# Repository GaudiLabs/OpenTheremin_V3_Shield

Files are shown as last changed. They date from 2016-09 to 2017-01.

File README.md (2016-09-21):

# OpenTheremin_V3_Shield
Open Source Theremin Instrument

Schematics, printed circuit board (PCB) design, bill of materials (BOM) for the Open.Theremin.V3 arduino shield.
For software see separate git repository.

### Don't click on the files!
Click on the "Download ZIP" Button to the right or [Click here](https://github.com/GaudiLabs/OpenTheremin_Shield/archive/master.zip) 
Then unpack the archive.

### Open Source Theremin based on the Arduino Platform

Open.Theremin.V3 is an arduino shield to build the legendary music instrument invented by Leon Theremin back in 1920. The theremin is played with two antennas, one to control the pitch and one for volume. The electronic shield with two ports to connect those antennas comprises two heterodyne oscillators to measure the distance of the hand to the antenna when playing the instrument. The resulting signal is fed into the arduino. After linearization and filtering the arduino generates the instruments sound that is then played through a high quality digital analog audio converter on the board. The characteristics of the sound can be determined by a wave table on the arduino.

For more info on the open source project and on availability of ready made shield see:

http://www.gaudi.ch/OpenTheremin/

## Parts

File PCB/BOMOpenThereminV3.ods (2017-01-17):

BOM OpenTheremin V3
Designator | Quantity | Package | Designation |  | Order No
U7 | 1 | SOIC-14_N | MCP4922-E/SL | mouser | 579-MCP4922T-E/SL
U4 | 1 | SOIC-14_N | AC74HC74 | mouser | 771-74HC74D-T
U5 | 1 | SOIC-14_N | CD4069 | mouser | 771-HEF4069UBTD-T
U2,U3 | 2 | SOIC-16_N | 74HC4060 | farnell | 771-74HC4060D-T ? / 2438691
U6 | 1 | SOIC-08_N | MCP4921-E/SN | mouser | 579-MCP4921T-E/SN
U8 | 1 | SOIC-08_N | MCP6002 (LM358) | mouser | 579-MCP6002T-I/SN
X1 | 1 | Crystal_HC49-SD_SMD | 8MHz | mouser | 717-9C-8.000MAAJ-T
X2 | 1 | Crystal_HC49-SD_SMD | 7.3721MHz | mouser | 717-9C-7.3728MAAJ-T
C2,C3, C9,C10 | 4 | 0805G | 150pF | mouser | 603-CC805JRNPO9BN151
C5, C12 | 2 | 0805G | 470pF | mouser | 603-CC805JRNPO9BN471
C15,C16,C17,C18 | 4 | 0805G | 33pF | mouser | 603-CC805JRNPO9BN330
C22 | 1 | 0805G | 47nF | mouser | 603-CC0805JR7BB473
C6,C13,C20,C21,C23, C24,C25,C26,C27,C28 | 10 | 0805G | 100nF | mouser | 603-CC805KRX7R8BB104
C29 | 1 | 0805G | 10uF | mouser | 603-CC805KRX5R5BB106
C1 | 1 | 0805G | 220pF | mouser | 603-CC805JRNPO9BN221
C8 | 1 | 0805G | 330pF | mouser | 603-CC805JRNPO9BN331
C4 | 1 |  | do not assemble
C11 | 1 | 0805G | 10pF | mouser | 603-CC805JRNPO9BN100
C7 |  |  | do not assemble
C14 |  |  | do not assemble
D1,D2 | 2 | SOT-23 | BB914 | mouser | 726-BB914E6327
D3 | 1 | LED | LED square 5mm red | Reichelt / ebay | L-1553HDT (V 530)
D4 | 1 | LED | LED square 5mm yellow | Reichelt / ebay | L-1553YDT (V 533)
L1,L2 | 2 | COIL | 1mH | mouser | 810-NL453232T-102JPF
R1,R5,R11,R13 | 4 | 0805G | 4.7M |  | 603-RC0805FR-074M7L
R12,R14 | 2 | 0805G | 470 |  | 603-RC0805FR-07470RL
R18,R19 | 2 | 0805G | 270 |  | 603-RC0805FR-07270RL
R2,R6 | 2 | 0805G | 2.2k |  | 603-RC0805FR-072K2L
R17 | 1 | 0805G | 2.2k |  | 603-RC0805FR-072K2L
R3,R4,R7,R8,R15,R16 | 6 | 0805G | 100k |  | 603-RC0805FR-07100KL
SW1 | 1 | SW_PUSH | Tactile Switches 12x12 SMT | Mouser / aliexpress / ebay | 706-95C12A4GWRT
P1,P2,P3,P4 | 4 | POT | 10k | mouser | 652-PTV09A-4020UB103 (104)
Y7 | 1 | PLUG3_5_SMD | Switchcraft, SMT 3.5 STEREO | mouser | 502-35RASMT2BHNTRX
Y3, Y4, Y5, Y6 | 1 | Pinheaders 2.54 |  | reichelt | SL 1X36G 2,54
 | 2 | Antenna Plug Standard |  | Reichelt / ebay | BS 40SA RT
 | 2 | Screw M3x10 |  | Hasler.ch /bossard | BN1435.03010
 | 2 | Nut M3 |  | Hasler.ch /bossard | BN117 M3
 | 2 | Washer |  | reichelt | SKZ 3,2-100
U1 | 1 | ArduinoUNO | Arduino_UNO_R2
 | 1 | PCB | OpenTheremin PCB V3
 |  |  |  |  | Urs Gaudenz, GaudiLabs 2017

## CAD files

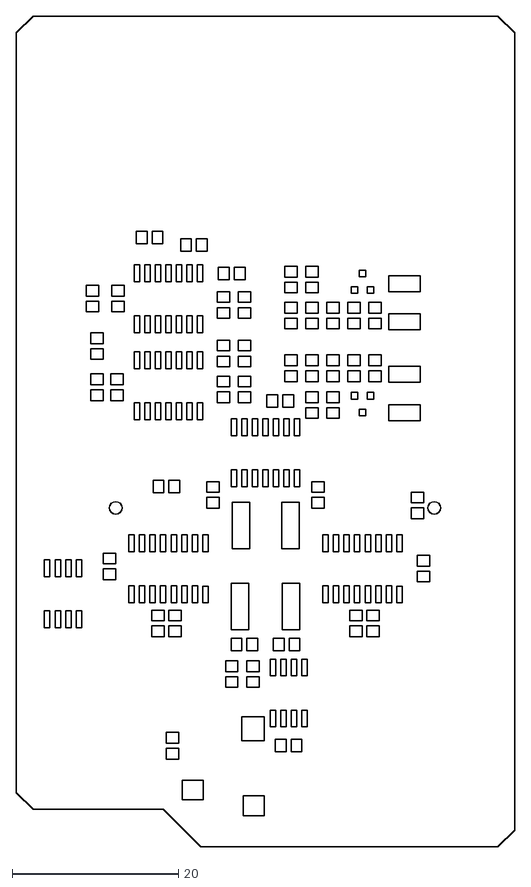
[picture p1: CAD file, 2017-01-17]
PCB/Stencli/Stencil.dxf
60.0 x 100.0

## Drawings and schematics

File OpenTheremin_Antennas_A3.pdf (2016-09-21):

# VOLUME ANTENNA

# Theremin Volume Connector

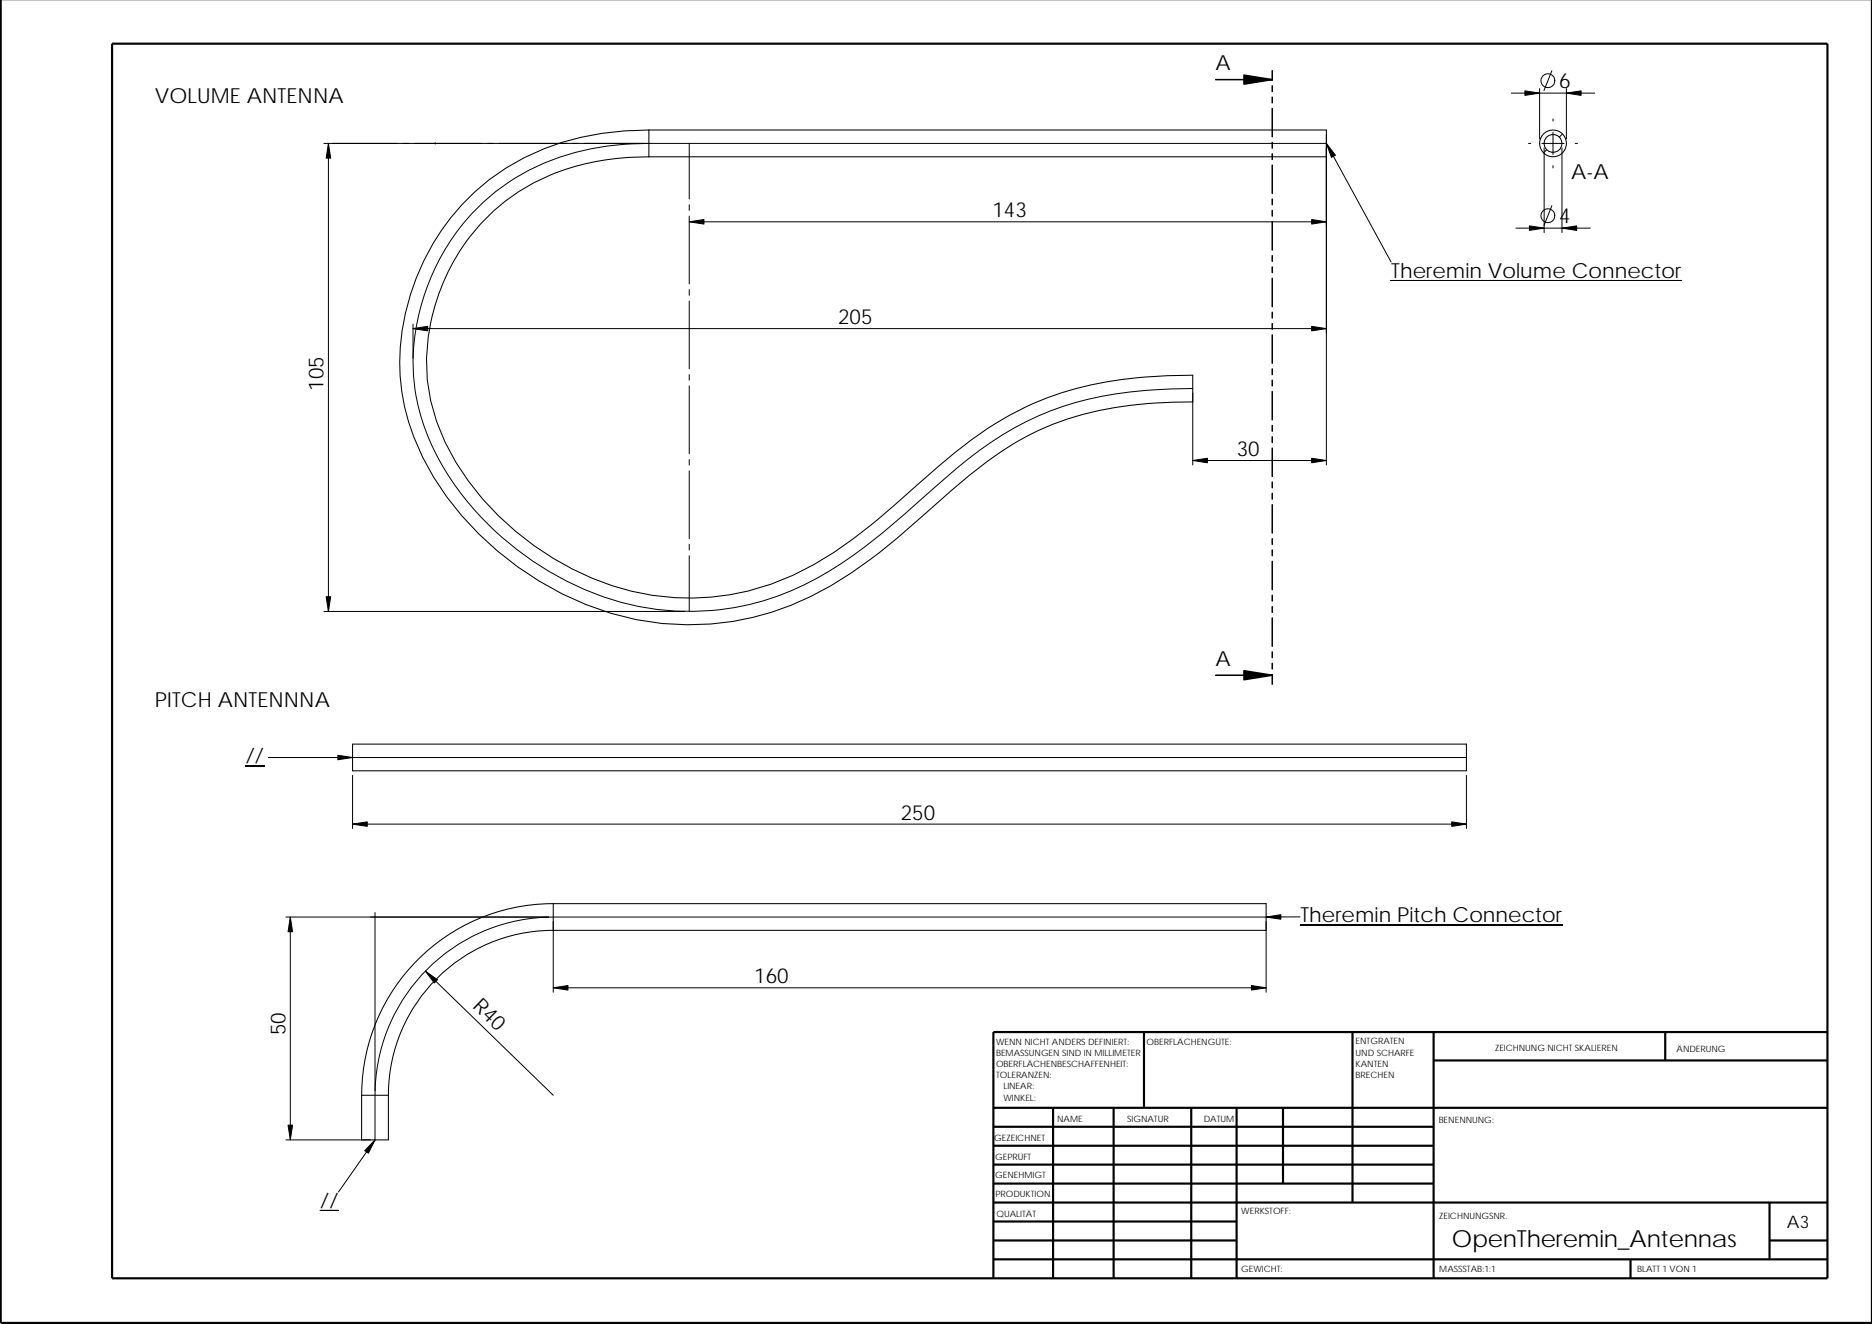
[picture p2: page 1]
PITCH ANTENNNA; GEWICHT:; MASSSTAB:1:1; BLATT 1 VON 1; ZEICHNUNG NICHT SKALIEREN; ÄNDERUNG; OBERFLÄCHENGÜTE:; ENTGRATEN; KANTEN BRECHEN; UND SCHARFE

Theremin Pitch Connector

WENN NICHT ANDERS DEFINIERT:
BEMASSUNGEN SIND IN MILLIMETER
OBERFLÄCHENBESCHAFFENHEIT:
TOLERANZEN:
LINEAR:
WINKEL:

NAME | SIGNATUR | DATUM | | | | BENENNUNG:

GEZEICHNET
GEPRÜFT
GENEHMIGT
PRODUKTION
QUALITÄT | | | | WERKSTOFF: | ZEICHNUNGSNR. OpenTheremin_Antennas | A3

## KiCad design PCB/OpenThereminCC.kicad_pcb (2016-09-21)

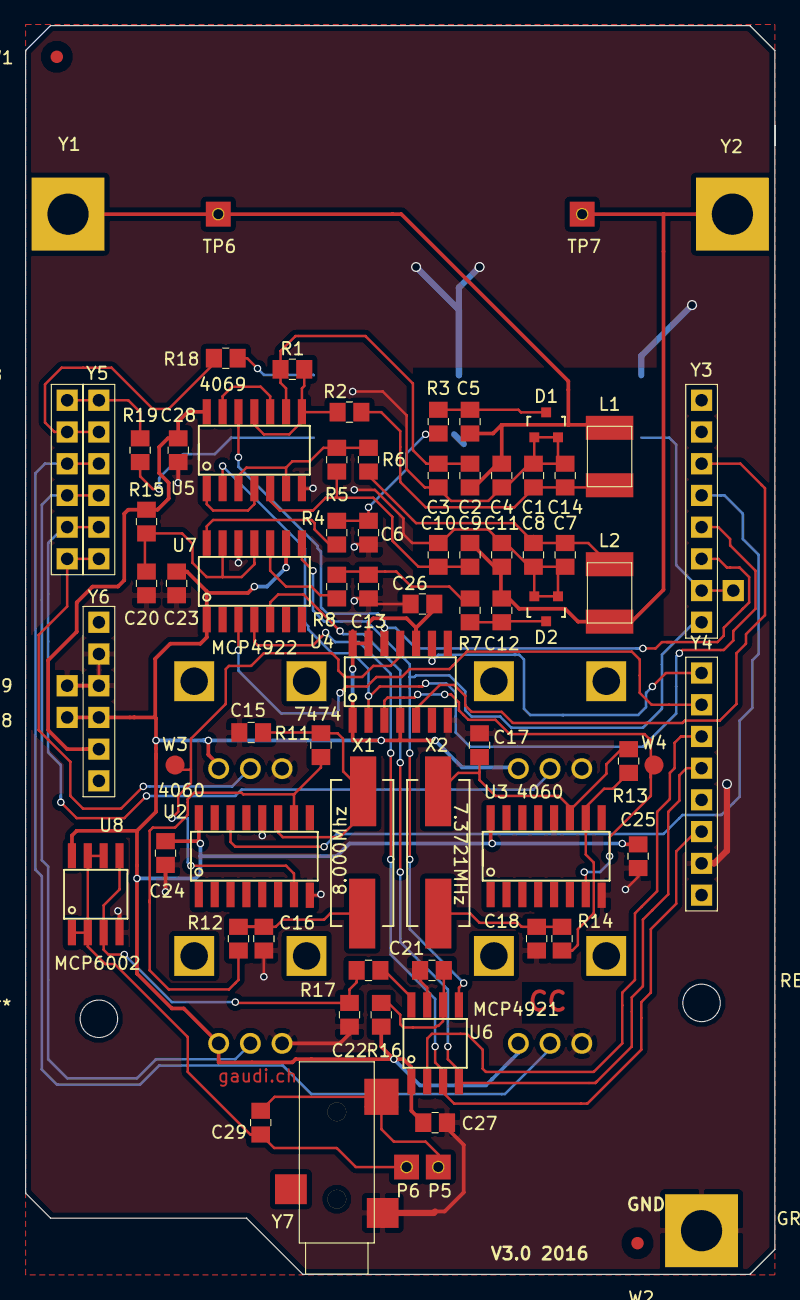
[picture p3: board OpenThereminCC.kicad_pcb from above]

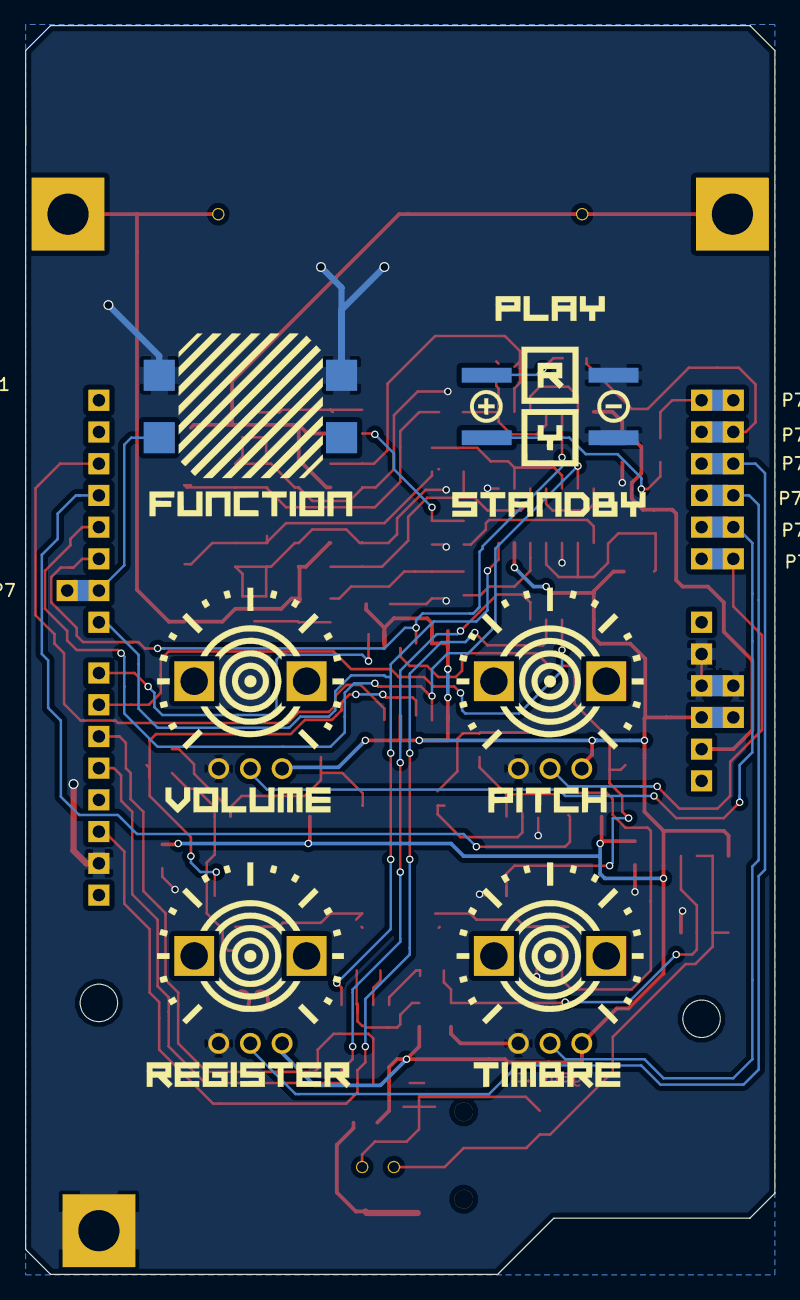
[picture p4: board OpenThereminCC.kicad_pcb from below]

Board: 2 copper layers, 60.0 x 100.0 mm, 95 parts (17 on the bottom side), 52 nets.

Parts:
C1: 220pF 270pF?; 0805G
C2, C3, C9, C10: 150pF; 0805G
C4: 15nF?; 0805G
C5, C12: 470pF; 0805G
C6, C13, C23, C24, C25, C26, C27, C28: 100nF; 0805G
C7, C14: ?pF; 0805G
C8: 330pF; 0805G
C11: 0; 0805G
C15, C16, C17, C18: 33pF; 0805G
C20, C21: 100n; 0805G
C22: 10n; 0805G
C29: 10uF; 0805G
D1, D2: BB914; SOT-23
D3, D4: LED; LED_SQUARE_5mm
GROUND1: GND_PAD; MountPad3
L1, L2: 1mH; COIL
P1, P2, P3, P4: 10k; POT
P5: SP+; MeasurePad_Square_wHole_2mm
P6: SP-; MeasurePad_Square_wHole_2mm
P7, P7#3, P7#4, P7#5, P7#6, P7#7, P7#8, P7#9, P7#10: CONN_01X01; SMD_Pinheader_1_OT_BLANK
P7#2, P8, P9: CONN_01X01; SMD_Pinheader_1_OT
R1, R5, R11, R13: 4.7M; 0805G
R2, R6, R17: 2.2k; 0805G
R3, R4, R7, R8, R15, R16: 100k; 0805G
R12, R14, R18, R19: 470; 0805G
SW1: SW_PUSH; PUSH_BUTTON_TL3300D
TP6: PITCH ANTENNA; MeasurePad_Square_wHole_2mm
TP7: VOLUME ANTENNA; MeasurePad_Square_wHole_2mm
U1: Arduino_UNO_R2; ArduinoUNO
U2, U3: 4060; SOIC-16_N
U4: 74HC74; SOIC-14_N
U5: 4069; SOIC-14_N
U6: MCP4921-E/SN; SOIC-08_N
U7: MCP4922-E/SL; SOIC-14_N
U8: LM358 / MCP6002; SOIC-08_N
W1: FIDUCIAL1; Fiducial_1mm_Dia_2.54mm_Outer_CopperTop
W2: FIDUCIAL2; Fiducial_1mm_Dia_2.54mm_Outer_CopperTop
W3: TP1; Measurement_Point_Round-SMD-Pad_Small
W4: TP2; Measurement_Point_Round-SMD-Pad_Small
X1: 8MHz; Crystal_HC49-SD_SMD
X2: 7.3721MHz; Crystal_HC49-SD_SMD
Y1, Y2: MountPad3
Y3, Y4: CONN_01X08; SMD_Pinheader_8_OT
Y5, Y6, Y8: CONN_01X06; SMD_Pinheader_6_OT
Y7: PLUG_3_5_SMD; PLUG3_5_SwitchCraft_2B

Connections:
A0: P1.2, Y5.6, Y8.6
A1: P2.2, Y5.5, Y8.5
A2: P3.2, Y5.4, Y8.4
A3: P4.2, Y5.3, Y8.3
BUT: P7#2.1, SW1.1, Y3.7
DAC2_CS: U7.3, Y4.2
DAC_CS: U6.2, Y4.3
DAC_DI: U6.4, U7.5, Y4.4
DAC_LATCH: U6.5, U7.8, Y3.8
DAC_SCK: U6.3, U7.4, Y4.6
F_PITCH: U4.9, Y4.1
F_VOL: U4.5, Y3.3
GND: C1.2, C3.2, C4.2, C6.2, C7.2, C8.2, C10.2, C11.2, C13.2, C14.2, C15.2, C16.2, C17.2, C18.2, C20.2, C21.2, C22.2, C23.2, C24.2, C25.2, C26.2, C27.2, C28.2, D1.1, D1.2, D2.1, D2.2, D3.1, D4.1, GROUND1.1, P1.1, P2.1, P3.1, P4.1, P9.1, SW1.2, U2.8, U2.12, U3.8, U3.12, U4.7, U5.7, U6.7, U7.12, U8.4, Y4.7, Y6.2, Y6.3, Y7.1
LED_GREEN: R18.2, Y5.2, Y8.2
LED_RED: R19.2, Y5.1, Y8.1
unnamed: C1.1, C14.1, L1.2, R2.1
unnamed: C2.1, C4.1, C5.1, L1.1, TP6.1, Y1.1
unnamed: C2.2, C3.1, R1.2, U5.9
unnamed: C5.2, D1.3, R3.2
unnamed: C6.1, R3.1, R4.1
unnamed: C7.1, C8.1, L2.2, R6.1
unnamed: C9.2, C10.1, R5.2, U5.5
unnamed: C9.1, C11.1, C12.1, L2.1, TP7.1, Y2.1
unnamed: C12.2, D2.3, R7.2
unnamed: C13.1, R7.1, R8.1
unnamed: C15.1, R11.2, U2.11, X1.1
unnamed: C16.1, R12.1, X1.2
unnamed: C17.1, R13.2, U3.11, X2.1
unnamed: C18.1, R14.1, X2.2
unnamed: C21.1, R16.1, U6.6
unnamed: C22.1, R17.2, U8.3, U8.5
unnamed: C29.1, P6.1, U8.1, U8.2, U8.6, U8.7
unnamed: C29.2, P5.1, Y7.3
unnamed: D3.2, R18.1
unnamed: D4.2, R19.1
unnamed: R1.1, R2.2, U5.8, U5.11
unnamed: R4.2, U7.14
unnamed: R5.1, R6.2, U5.3, U5.6
unnamed: R11.1, R12.2, U2.10
unnamed: R13.1, R14.2, U3.10
unnamed: R17.1, U6.8
unnamed: U2.7, U4.11, W3.1
unnamed: U3.7, U4.3, W4.1
unnamed: U5.1, U5.4
unnamed: U5.10, U5.13
SAMPLE_CLK: U2.14, Y3.4
VCC: C23.1, C24.1, C25.1, C26.1, C27.1, P1.3, P2.3, P3.3, P4.3, P8.1, R16.2, U2.16, U3.16, U4.1, U4.4, U4.10, U4.13, U4.14, U6.1, U7.1, U7.9, U8.8, Y6.4
VDD: C28.1, R15.2, U5.14, Y6.5
VO_PITCH: U4.12, U5.12, Y3.6
VO_VOL: U4.2, U5.2, Y3.5
VoutB: R8.2, U7.10
VrefB: C20.1, R15.1, U7.11, U7.13

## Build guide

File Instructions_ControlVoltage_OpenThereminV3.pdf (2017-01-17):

### How to set up the Open.Theremin V3 for Control Voltage

The Open.Theremin is a stand alone instrument that generates sounds in different waveforms when played. Eight waveforms can be selected through the TIMBRE knob on the board. These waveforms can be reprogrammed using different software available online. To even further expand the possibilities the Open.Theremin can be set in “Control Voltage Mode” to control any sound synthesizer with an analog control voltage input (CV).

When in control voltage mode the signal of the pitch antenna is translated into an analog signal that will be output through the audio-jack on the board. The audio sound will not be available anymore. However you can always reinstall the original software to go back to normal audio-mode. The volume signal is not available on control voltage for now.

So here is how to set the Open.Theremin to control voltage mode:

1. You need to solder a pair of pinheaders to the free pads (P5 + P6) next to the audio-jack and install a jumper. You can find these jumpers in many electronic stores. Alternatively you can solder in a switch or just a short piece of cable to make the short between the two pads.

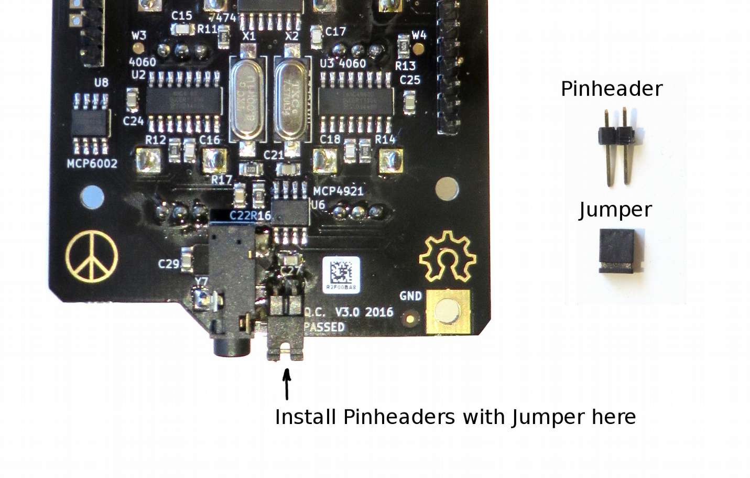
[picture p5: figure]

2. Now you need to re-upload the software with the modification for the control voltage mode. With the newest Open.Theremin V3 software loaded in the Arduino IDE go to the tab named “build.h” and change the following line from a 0 to a 1

#define CV_ENABLED 1

Now re-upload the software (for details see the Open.Theremin V3 instruction manual).

Your theremin will now generate analog values in the range of 0-5 V on the left channel of the audio jack. Maybe you want to recalibrate the theremin by pressing the FUNCTION button for 3 seconds. The PITCH and REGISTER button can still be used to change the zero beat and sensitivity respectively.

For more information, documentation and source code of the open design go to: www.gaudi.ch/OpenTheremin

Open.Theremin Instruction by Urs Gaudenz, licensed under a Creative Commons Attribution 4.0 International License.
25. Oct. 2016

Additional advanced instructions:

If you want to adapt the output signal to your specific needs you can do this by modifying the following lines of code (in the “ihandlers.cpp” tab):

#if CV_ENABLED | // Generator for CV output

vPointerIncrement = min(vPointerIncrement, 4095); // vPointerIncrement is the signal of the pitch antenna mcpDacSend(vPointerIncrement); //Send result to Digital to Analogue Converter (audio out)

#else //Play sound

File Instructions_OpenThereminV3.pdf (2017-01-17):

### Open.Theremin V3 Kit

Congratulations, this is your Open.Theremin V3, the newest version of a DIY Theremin used by more than 1000 people around the world today. Happy to have you in the community of people exploring the amazing instrument initially conceived by Leon Theremin. This is a digital theremin shield for the Arduino UNO based on the original principle of heterodyne oscillators.

Some instruction on how to set it up and get the best out of the circuit:

This is the content of your Kit:

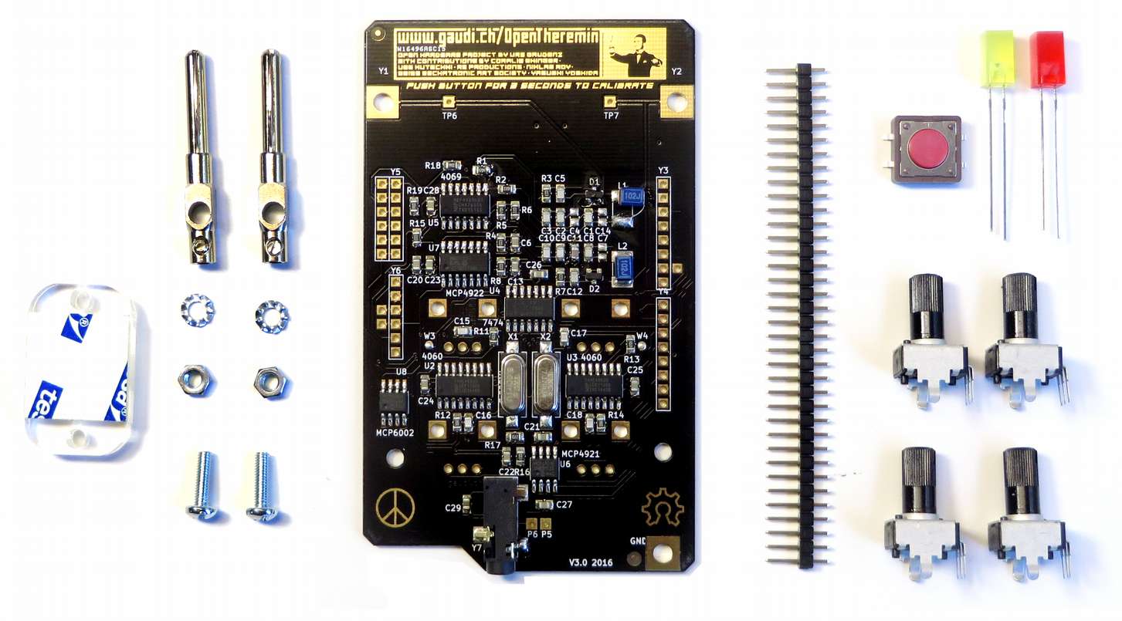
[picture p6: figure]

Mechanical Parts | Theremin Circuit Board | Electronic Components
1. Complete the shield

First solder in the pins that connect the shield to the Arduino as shown in the picture below.

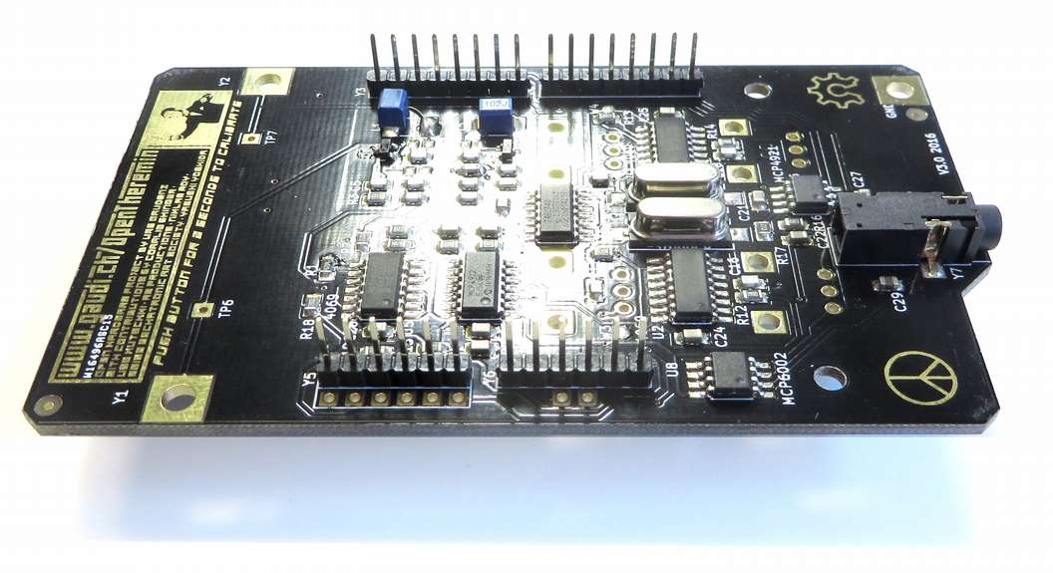
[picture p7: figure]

Next solder the push button and the two LEDs to the front. A good soldering technique for these surface mounting parts is to first put a bit of solder on one pad, then heat the solder and slide the component in place. Then solder the rest of the pads. The LED-lights have a plus and minus leg. The leg that goes to the plus side is longer. Bend the two legs of the LED to the outside and cut them to the right length. See the drawing.

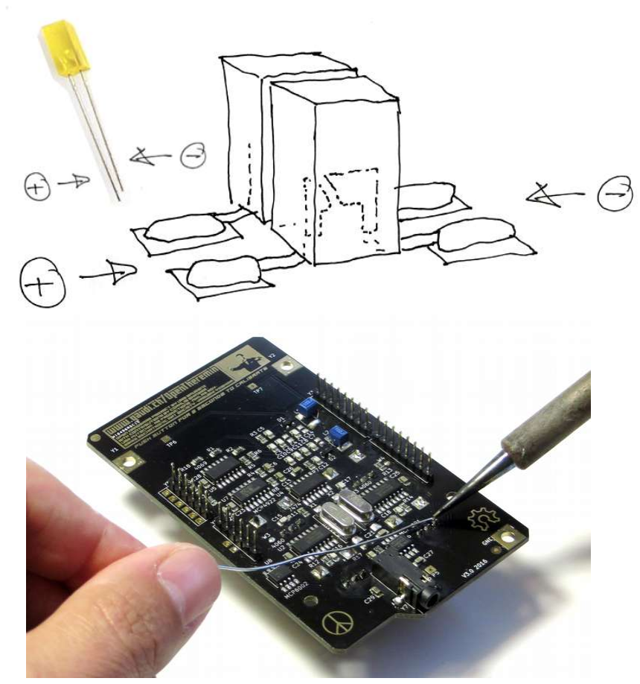
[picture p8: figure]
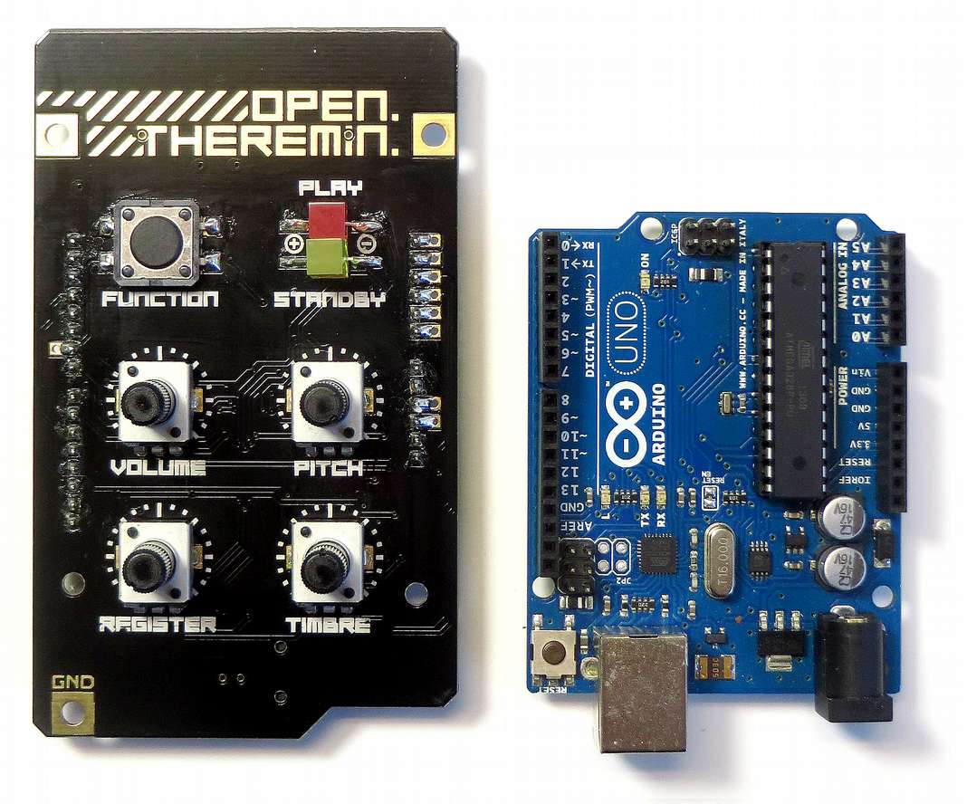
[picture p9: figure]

Finally add the four potentiometers and solder them carefully on the backside. Be sure to only put solder on the pads for the potentiometers.

Now you are ready to connect the shield on top of an Arduino UNO. Arduino UNO is a very popular open source electronic development platform that you can get from many sources on the Internet. See here for Resellers: www.arduino.cc/en/Main/Buy

2. Connect Antennas to the Open.Theremin

You can basically use any electrically conductive material as antennas. The picture shows how to connect two aluminum rods (can be found in most hardware stores) with an inner diameter of 4 mm using the supplied spring plugs (banana plugs). The total length per antenna should be around 40 to 50 cm. You can easily bend antennas form aluminum tubes of 6 mm diameter by hand to the desired shape. To build the theremin into a case you can also use stiff wire to connect the antennas.

Volume Antenna | Pitch Antenna

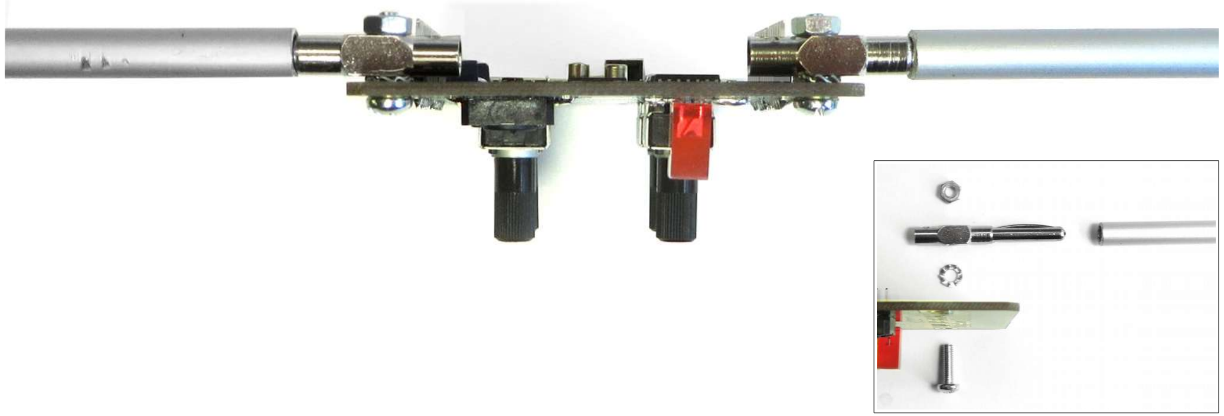
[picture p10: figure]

3. Connect the Audio Out

Use the mini jack connector on the bottom of the open.theremin shield to connect an amplifier or an active speaker.

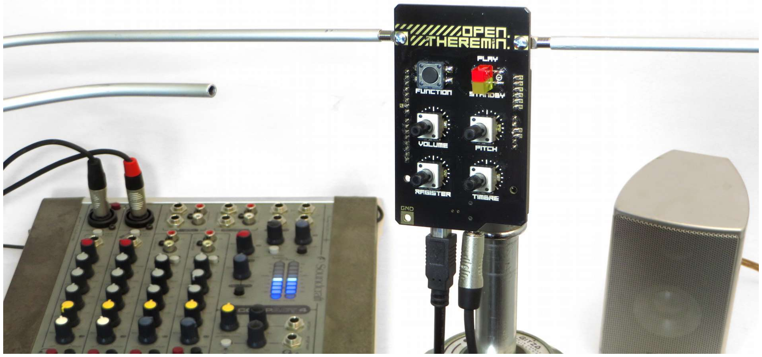
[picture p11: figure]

4. Set up and Grounding

The theremin measures smallest variations of capacities (less than 1 pico Farad). The capacity between the antenna and your hand is measured and translated into the pitch (or the volume) of the sound. The electric loop with the instrument is closed from your hand through your body, through your shoes through the floor into the ground and from ground back into the instrument. This is why proper grounding of the instrument is important.

Use any of the following methods to ground your theremin.

a. Use a grounded audio cable. If you connect your theremin to a mixer or amplifier that is grounded, the theremin is grounded through the audio cable.
b. Use a grounded power supply. You can power your theremin through the USB plug (by a device like a computer or a power adapter with USB connector) or by a separate power adapter. If the power supply is grounded the theremin is grounded as well. Notice that many USB power adapter and power supplies are not grounded.
c. Use a separate grounding wire. There is a ground pad (GND) on the open.theremin board where you can connect an extra grounding wire. Attach this wire to a grounded metallic object in your room (like a lamp or a water tube).

And not only your body is interfering with instrument,

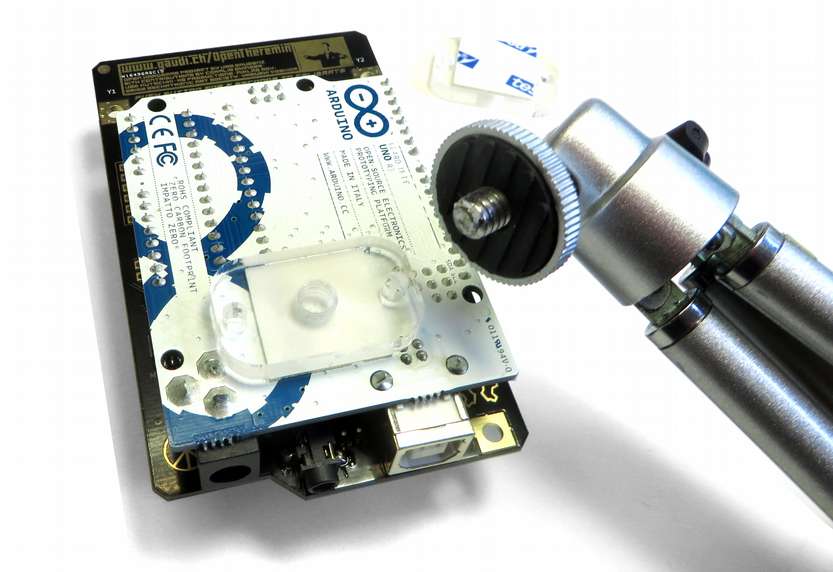
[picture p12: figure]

also a table or an object close to the theremin will add to the capacity sensed by the instrument. So best is to put up the theremin on a stand in the open space. The little acrylic adapter piece with a threaded hole (supplied in the kit) fits to commercial camera stands (1/4" UNC) and can be sticked to the back of the arduino or your own housing.

5. Programing the arduino

Connect the Arduino UNO to the computer using a standard USB cable. Note that the LED-light will only light up when the Arduino is programmed. For this download the latest Arduino IDE Software and the Open.Theremin V3 code form the links below and upload it to the board. When the upload is successful you should see the red LED-light turn on.

Instruction on how to install the Arduino programming tool and how to use it can be found here: http://arduino.cc/en/Guide/HomePage

Get the Open Theremin Code from the Git-Hub Repository by clicking the “Download ZIP” Button on this site: https://github.com/GaudiLabs/OpenTheremin_V3

6. Auto-calibration of the theremin

Theremins are very sensitive devices. This is why they need calibration before playing. The new open.theremin V3 has an electronic auto calibration built in, it makes calibration very easy. To do so follow these steps:

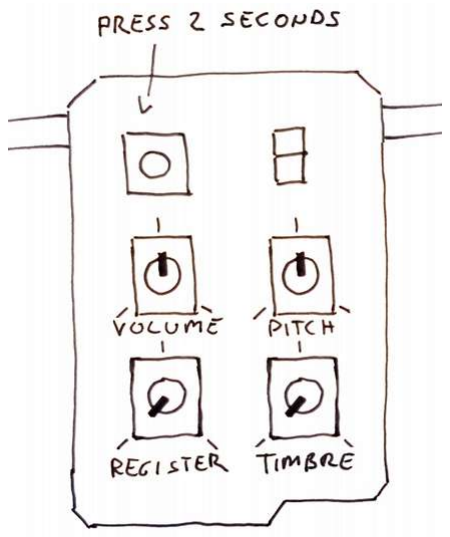
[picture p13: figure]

a. Power the theremin and let it warm up for about 10 minutes.
b. Now turn the two knobs VOLUME and PITCH to the middle position and the knobs REGISTER and TIMBRE all to the left.
c. Press the FUNCTION button on the theremin shield for about 2 second until you hear a short melody. The yellow LED-light will now start blinking and the theremin does the automatic calibration of the antennas. To not disturb the calibration step away form the theremin and wait until the red LED-light goes back on.

Now you theremin is ready to play.

The calibration values are stored in the Arduino. So you only have to do this procedure once. If however you move your theremin or feel that it is not playing well, you can always repeat the procedure to re-calibrate.

Functionality of the knobs:

The PITCH knob allows you to fine adjust the playing range of the pitch antenna (zero beat). The VOLUME changes the sensitivity of the volume antenna.
For a good introduction on how to tune the theremin see this excellent introduction by Carolina Eyck: https://youtu.be/A48fm1ZEgZU

With the REGISTER knob you can vary the sensitivity of the theremin. Turn it to the right to increase sensitivity. Note that higher sensitivity may come with more noise picked up by the antenna.

The TIMBRE knob allows you to choose from one out of 8 different sound settings.

You can mute your theremin by pressing the FUNCTION button.

For more information, documentation and source code of the open design go to: www.gaudi.ch/OpenTheremin

Open.Theremin Instruction by Urs Gaudenz, licensed under a Creative Commons Attribution 4.0 International License.

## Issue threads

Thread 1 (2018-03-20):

PCB Component and Footprint libraries missing

NathanSchenk, 2018-03-20:
In order to edit the schematic and PCB easily, KiCad needs the GaudiLabsFootprints and the GaudiLabsPartsLibrary.

Would it be possible to add these as GitHub repositories?

Thanks for your good work!

NathanSchenk, 2018-03-20:
Looks like I found the libraries in your OpenDrop repo.  They probably should still be added to this repo, or at least the location mentioned in readme.md

Thanks again, good work!

GaudiLabs, 2018-03-20:
These are libraries with many parts for all kind of projects. Is there a way to pull out only the parts that belong to the project?

Urs

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

--
Sent from my Android device with K-9 Mail. Please excuse my brevity.

NathanSchenk, 2018-03-22:
I believe the libraries could be manually adjusted, or maybe a script created to automatically trim the libraries..  I'll look into that after I'm done with my current project, unless you beat me to it!

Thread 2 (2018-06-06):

Variable capacitor - digikey discontinued

patricksebastien, 2018-06-06:
Hi,

Do you think this replacement for **490-7155-ND** will work:
https://www.digikey.ca/product-detail/en/knowles-voltronics/JZ300/1674-1005-1-ND/6021644

Thanks

patricksebastien, 2018-09-06:
Not used in V3. Closing...

Closed 2018-09-06.

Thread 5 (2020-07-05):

Wrong component values on BOM file

miguelfreitas, 2020-07-05:
Hi @GaudiLabs, I have started soldering the components for OpenTheremin V3 (ordered them from Mouser using the BOM file) and I have found two errors so far.

1. C22 is listed as 47nF in BOM however schematics show 10nF. Checking the RC filter frequency, 10nF seems the right one (Fc=7.2kHz). With 47nF we'd get Fc=1.5kHz which seems way too low.

2. R18, R19 are listed as 270R in BOM however schematics show 470R. Not a big deal. Provided arduino is able to provide enough current the led will be brighter :-)

Btw, I have also rerouted the PCB for increasing the via drill to 0.5mm and track widths / clearance to 0.35mm. These where requirements for one PCB house I've tried. I have not yet tested if the new PCB works, hopefully I didn't broke anything. I will probably fork and commit it to a new repo.

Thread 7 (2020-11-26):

SCH and BRD files not compatible with newest KiCAD (5.1.7)

abstring, 2020-11-26:
Schematic and board files do not appear to be compatible with KiCAD 5.1.7. See error messages attached.
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

abstring, 2020-11-26:
This applies to the V1 link referenced in the readme. The V3 version works fine if downloaded directly from GitHub.

Closed 2020-11-26.

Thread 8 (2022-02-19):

Antenna connector

Jap8nted, 2022-02-19:
Hi all,

I live in Germany and have no idea how to find the antenna connectors. How are they called and where could I buy something like that.

Do you guys have any hint?

GaudiLabs, 2022-02-19:
Hi
They are called banana connectors. you find them at reichelt. de

Urs

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
🧪 GaudiLabs LLC
Urs Gaudenz
Email: ***@***.***
www.gaudi.ch

Jap8nted, 2022-02-19:
Thank you so much

Closed 2022-02-19.

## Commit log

2016-09-21 Secont prototype of Version 3 PCB
    Now testing...
    [OpenThereminCC-B.Cu.gbr, OpenThereminCC-B.Mask.gbr, OpenThereminCC-B.Paste.gbr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]
2017-01-17 Update batch 2, OSHW certificate, CV instruction
    [BOMOpenThereminV3.ods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]
